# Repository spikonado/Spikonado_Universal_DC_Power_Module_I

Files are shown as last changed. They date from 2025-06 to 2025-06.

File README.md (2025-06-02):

# Spikonado Universal DC Power Module I

The [Spikonado Universal DC Power Module I](https://spikonado.com/product/spikonado-universal-dc-power-module-i) is a versatile and high-current buck converter designed to power your most demanding electronics projects. It efficiently (92.7%) converts a wide **13-24** DC input into three stable, dedicated outputs:

- **12V @ 4A**
- **5V @ 10A**
- **3.3V @ 8A**

This module is perfect for robotics, embedded systems, single-board computers (SBCs), custom test jigs, and any application requiring reliable multi-voltage power.<br>
Further enhancing its flexibility, the board includes USB-C and USB-A outputs.<br>
What's more, we have also included EN and PG pins through which you can control the board using a microcontroller and also attach a switch to the board.

The board also includes the following protections:

1. Over Current Limit (OCL) - Protects the board from overloads by limiting the output current.
2. Undervoltage Lockout (UVLO) - When the input voltage on VIN falls below the required voltage, the particular voltage output shuts off.
3. Thermal Shutdown - When any of the buck converter ICs included on the board get too hot, the particular voltage output shuts off.
4. Undervoltage and Overvoltage Protection (UVP & OVP) (Not included for 12V output) - When the output voltage falls too low or goes too high than the desired voltage, the output is discharged and latched.

## 📂 About this Repository

This repository is your central hub for all information, design files, and resources related to the Spikonado Universal DC Power Module I. Our aim is to provide everything you need to understand, use, and even build upon this product.

You'll find:

- `docs/`: Comprehensive documentation, including datasheets, specifications, and user guides.
- `hardware_design/`: Complete KiCad project design files – schematics and PCB layout for the board.

## Accessing the Documentation

The `docs/` directory contains the source files for our comprehensive product documentation. For the best reading experience, with all formatting and interactive elements correctly rendered, please view the built version on our [website](https://docs.spikonado.com/Spikonado_Universal_DC_Power_Module_I).

While you can browse the raw files in the `docs/` directory on GitHub, they are primarily intended for those contributing to the documentation or exploring its source structure.

## 🤝 Contributing

Contributions, issues, and feature requests are welcome! Feel free to check existing issues or open a new one.

## 📄 License

This product is open source!

Please review the following files for license information:

- `hardware_design/LICENSE.md`

If you have any questions or concerns related to licensing, please email support at support@spikonado.com.

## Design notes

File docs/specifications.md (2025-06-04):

# Specifications

## Maximum Current Ratings

- USB-A Outputs: 1.5A
- USB-C Outputs: 5A (Detected as 3A by smart devices connected to it)
- Scew Terminals: Same as the maximum current rating for their specific votage output
- PG: Less than 20mA

## Design Specifications

- [3D Model](https://github.com/spikonado/Spikonado_Universal_DC_Power_Module_I/blob/main/hardware_design/Spikonado_Universal_DC_Power_Module_I/Spikonado_Universal_DC_Power_Modul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)
- [Board Dimensions](https://github.com/spikonado/Spikonado_Universal_DC_Power_Module_I/blob/main/hardware_design/Spikonado_Universal_DC_Power_Module_I/dimensions.pdf)
- [Board Circuit Schematic](https://github.com/spikonado/Spikonado_Universal_DC_Power_Module_I/blob/main/hardware_design/Spikonado_Universal_DC_Power_Module_I/schematic.pdf)

## More Specifications

Datasheets of the buck converter ICs used in this board:

- 12V Output -> [LMR33640ADDAR](https://www.ti.com/lit/ds/symlink/lmr33640.pdf)
- 5V Output -> [TPS51396ARJER](https://www.ti.com/lit/ds/symlink/tps51397a.pdf)
- 3.3V Output -> [TPS51396ARJER](https://www.ti.com/lit/ds/symlink/tps51396a.pdf)

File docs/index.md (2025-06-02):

<script type="module" src="https://ajax.googleapis.com/ajax/libs/model-viewer/3.5.0/model-viewer.min.js"></script>

# Overview and Basic Usage

The [Spikonado Universal DC Power Module I](https://spikonado.com/product/spikonado-universal-dc-power-module-i) is a versatile and high-current buck converter designed to power your most demanding electronics projects. It efficiently (92.7%) converts a wide **13-24V** DC input into three stable, dedicated outputs:

- **12V @ 4A**
- **5V @ 10A**
- **3.3V @ 8A**

<figure markdown>
  <model-viewer alt="3D View of Spikonado Universal DC Power Module I" src="./assets/3d_model/Spikonado_Universal_DC_Power_Module_I.glb" camera-controls autoplay style="width: 500px; height: 300px;">
  </model-viewer>
  <figcaption markdown>3D View of Spikonado Universal DC Power Module I</figcaption>
</figure>

This module is perfect for robotics, embedded systems, single-board computers (SBCs), custom test jigs, and any application requiring reliable multi-voltage power.<br>
Further enhancing its flexibility, the board includes USB-C and USB-A outputs.<br>
What's more, we have also included EN and PG pins through which you can control the board using a microcontroller and also attach a switch to the board.

The board also includes the following protections:

1. Over Current Limit (OCL) - Protects the board from overloads by limiting the output current.
2. Undervoltage Lockout (UVLO) - When the input voltage on VIN falls below the required voltage, the particular voltage output shuts off.
3. Thermal Shutdown - When any of the buck converter ICs included on the board get too hot, the particular voltage output shuts off.
4. Undervoltage and Overvoltage Protection (UVP & OVP) (Not included for 12V output) - When the output voltage falls too low or goes too high than the desired voltage, the output is discharged and latched.

## Setting it Up

You must have recieved the following components in your package, when ordering from us:

1. [Spikonado Universal DC Power Module I](https://spikonado.com/product/spikonado-universal-dc-power-module-i) - x1
2. 2.54mm 1x2 Pin Male Header Strip - x3
3. 2.54mm 1x2 Pin Female Header Strip - x3
4. 2.54mm 1x1 Pin Male Header Strip - x3
5. 2.54mm 1x1 Pin Female Header Strip - x3
6. 5.0mm 1x2 Pin Screw Terminal Block - x4
7. 2.54mm 1x2 Pin Female Jumper - x3

Solder the headers and screw terminals onto your board as you desire.<br>
After soldering, it is recommended to use a multimeter to check that no shorts have been made by you during the soldering process.

Then, on the 3 EN pin pairs attach the jumpers or make a solder connection (not recommended) between the 2 pins of each pair if you aren't soldering the EN male headers onto your board. If soldering the female headers, you can also use male to male jumper wires to make the connection.

## Basic Usage

You need to first solder / screw (Screw Terminal) in two wires from your DC power output (ex. battery pack or wall adapter), into the VIN and GND ports of the board.<br>
You should now see all the 3 LEDs on the output terminals of the board lit, this means that all the outputs are working.<br>
You can now connect any DC load onto the output terminals of the board by soldering, screwing (Screw Terminal) or plugging (USB-C / USB-A) it in.

## Next Steps

Have a look at [What are EN and PG?](what_are_en_and_pg.md) to learn how to use those pins.<br>

## Related Resources

Have a look at [Specifications](specifications.md) to know more about the board's inner circuit alongside precise information on voltage and current ratings.

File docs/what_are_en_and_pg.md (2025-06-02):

# What are EN and PG?

## EN - Enable

There are 3 pairs of EN pins on the board. EN1 for 12V, EN2 for 5V, and EN3 for 3.3V.

You are supposed to short every pair of pins in order to turn on the respective outputs. So, if for example, you would like to add a switch to the board, you can simply connect it between the two pins. Whenever the switch is off, that particular voltage output will be off and when it is on, that particular voltage output will be on.

You can also control this on and off functionality through a microcontroller's digital / GPIO pins by simply not shorting the EN pair of pins together and instead connecting the digital / GPIO pin of your microcontroller to the pin right under which the EN label is.<br>
By simply setting the pin's mode to OUTPUT and turning the pin HIGH (1.2V to 5.5V) and LOW (-0.3V to 0.3V), you can turn the buck converter's voltage outputs on and off respectively.

## PG - Power Good

There are 3 PG pins on the board. PG1 for 12V, PG2 for 5V, and PG3 for 3.3V.

You can connect these pins to a microcontroller's pins and set the mode of the latter to INPUT.

The PG pins output LOW (0V) during fault conditions like OVP, UVP, UVLO, and thermal shutdown or when the converter is off / starting. Do note that the PG pins do not output LOW during Over Current Limit (OCL).<br>
The rest of the time the PG pins output HIGH (3.2 to 3.4, usually 3.3).

The PG output and status of each buck converter included in the board (12V, 5V, 3.3V) is different, one of the voltage outputs may be under fault conditions while the others may be wokring just fine.

## Related Resources

You can look at [Specifications](specifications.md) to know more about when the various fault conditions are triggered and to also know the startup time for each voltage output.

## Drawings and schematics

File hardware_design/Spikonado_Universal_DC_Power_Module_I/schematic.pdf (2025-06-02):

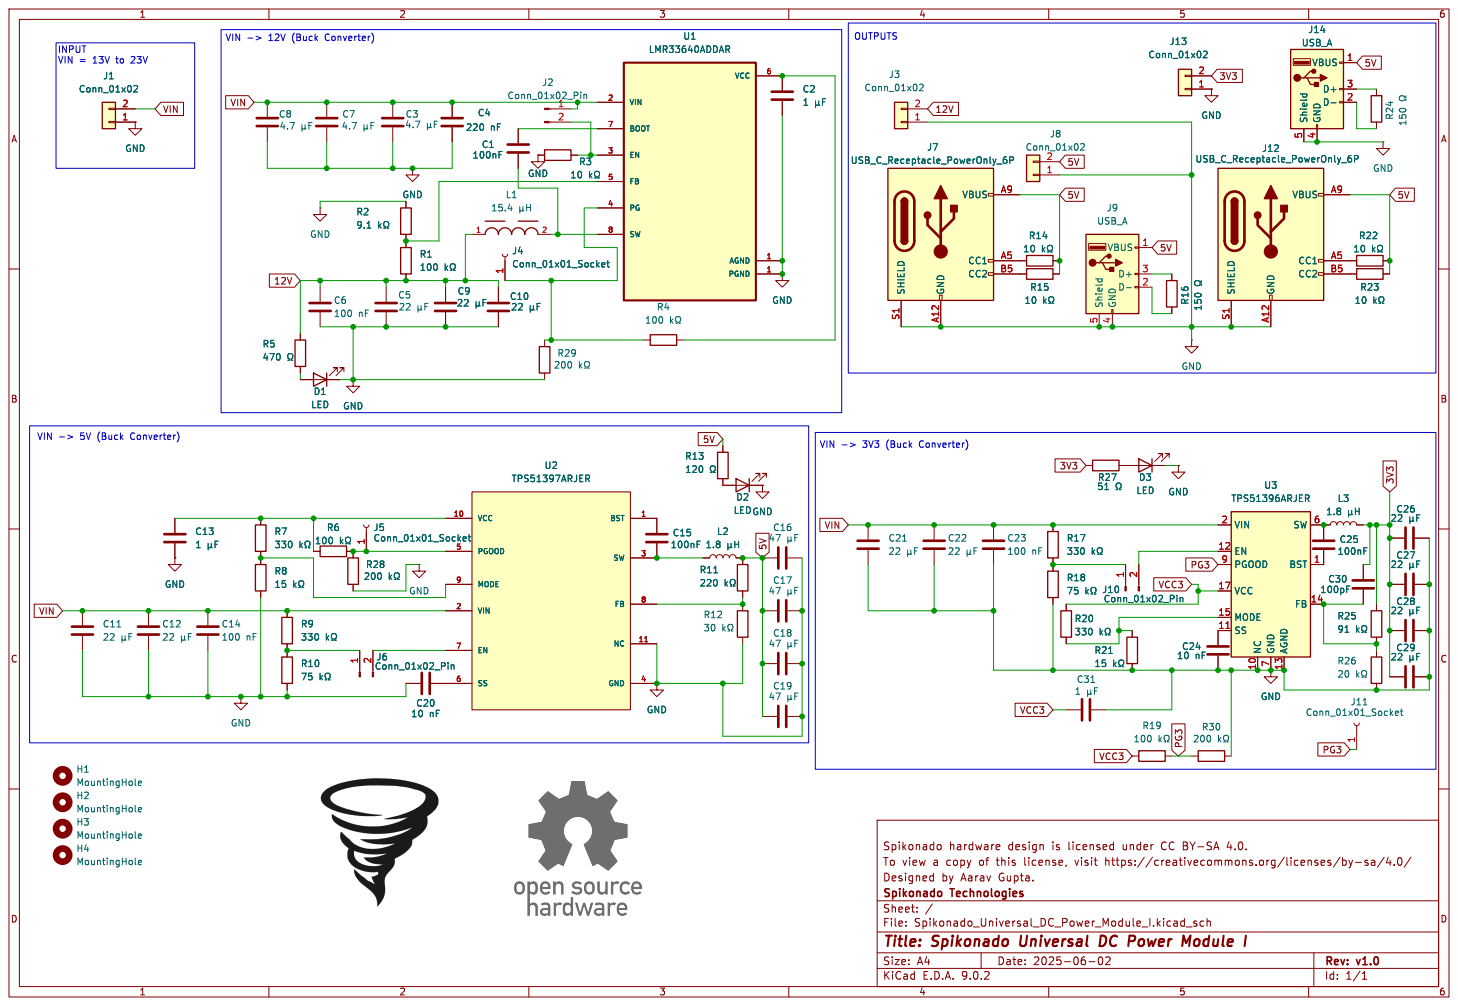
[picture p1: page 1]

INPUT VIN = 13V to 23V GND

10 þÿk© GND R16 150 þÿ© GND Shield

7 FB 14 VCC 17 SS 11 NC 10 AGND 13 SW 6 BST 1 U3 TPS51396ARJER

7 FB 14 VCC 17 SS 11 NC 10 AGND 13 SW 6 BST 1 R18

Designed by Aarav Gupta. To view a copy of this license, visit | | https://creativecommons.org/licenses/by-sa/4.0/

Technologies Id: 1/1 Title: Spikonado Universal DC Power Module I File: Spikonado_Universal_DC_Power_Module_I.kicad_sch Sheet: / Spikonado

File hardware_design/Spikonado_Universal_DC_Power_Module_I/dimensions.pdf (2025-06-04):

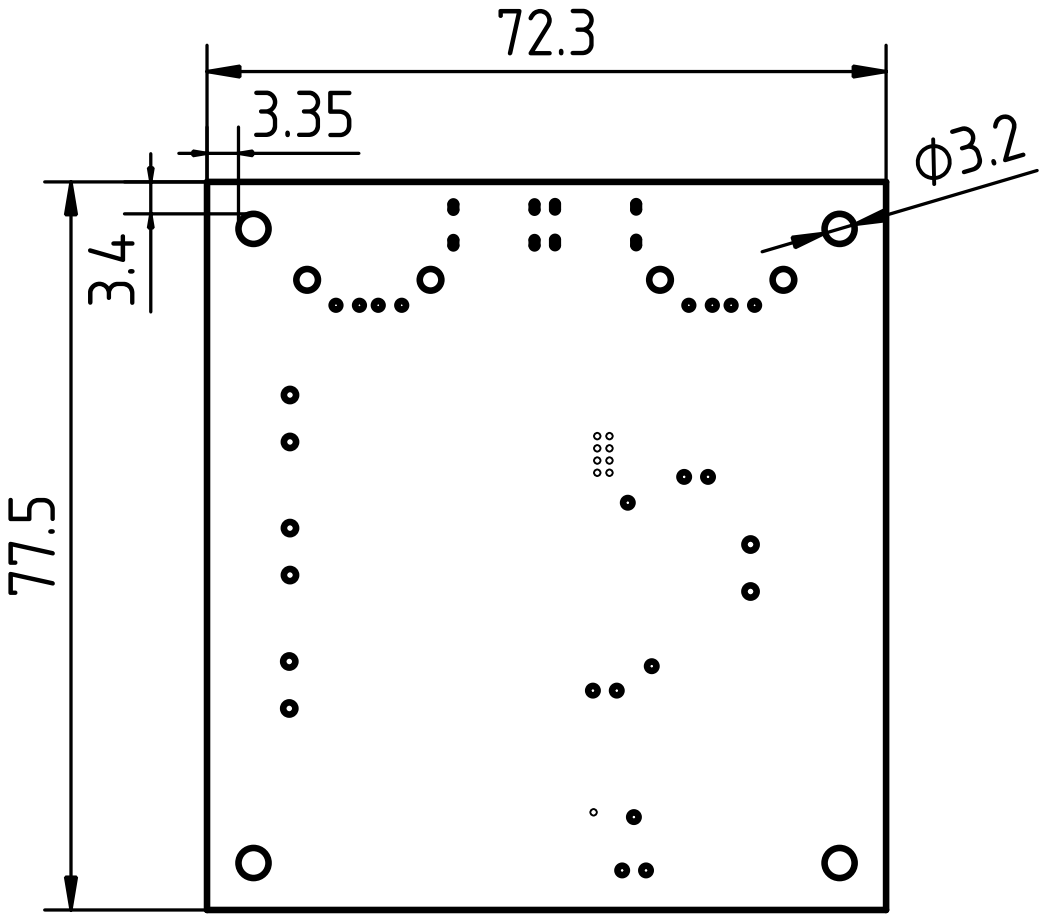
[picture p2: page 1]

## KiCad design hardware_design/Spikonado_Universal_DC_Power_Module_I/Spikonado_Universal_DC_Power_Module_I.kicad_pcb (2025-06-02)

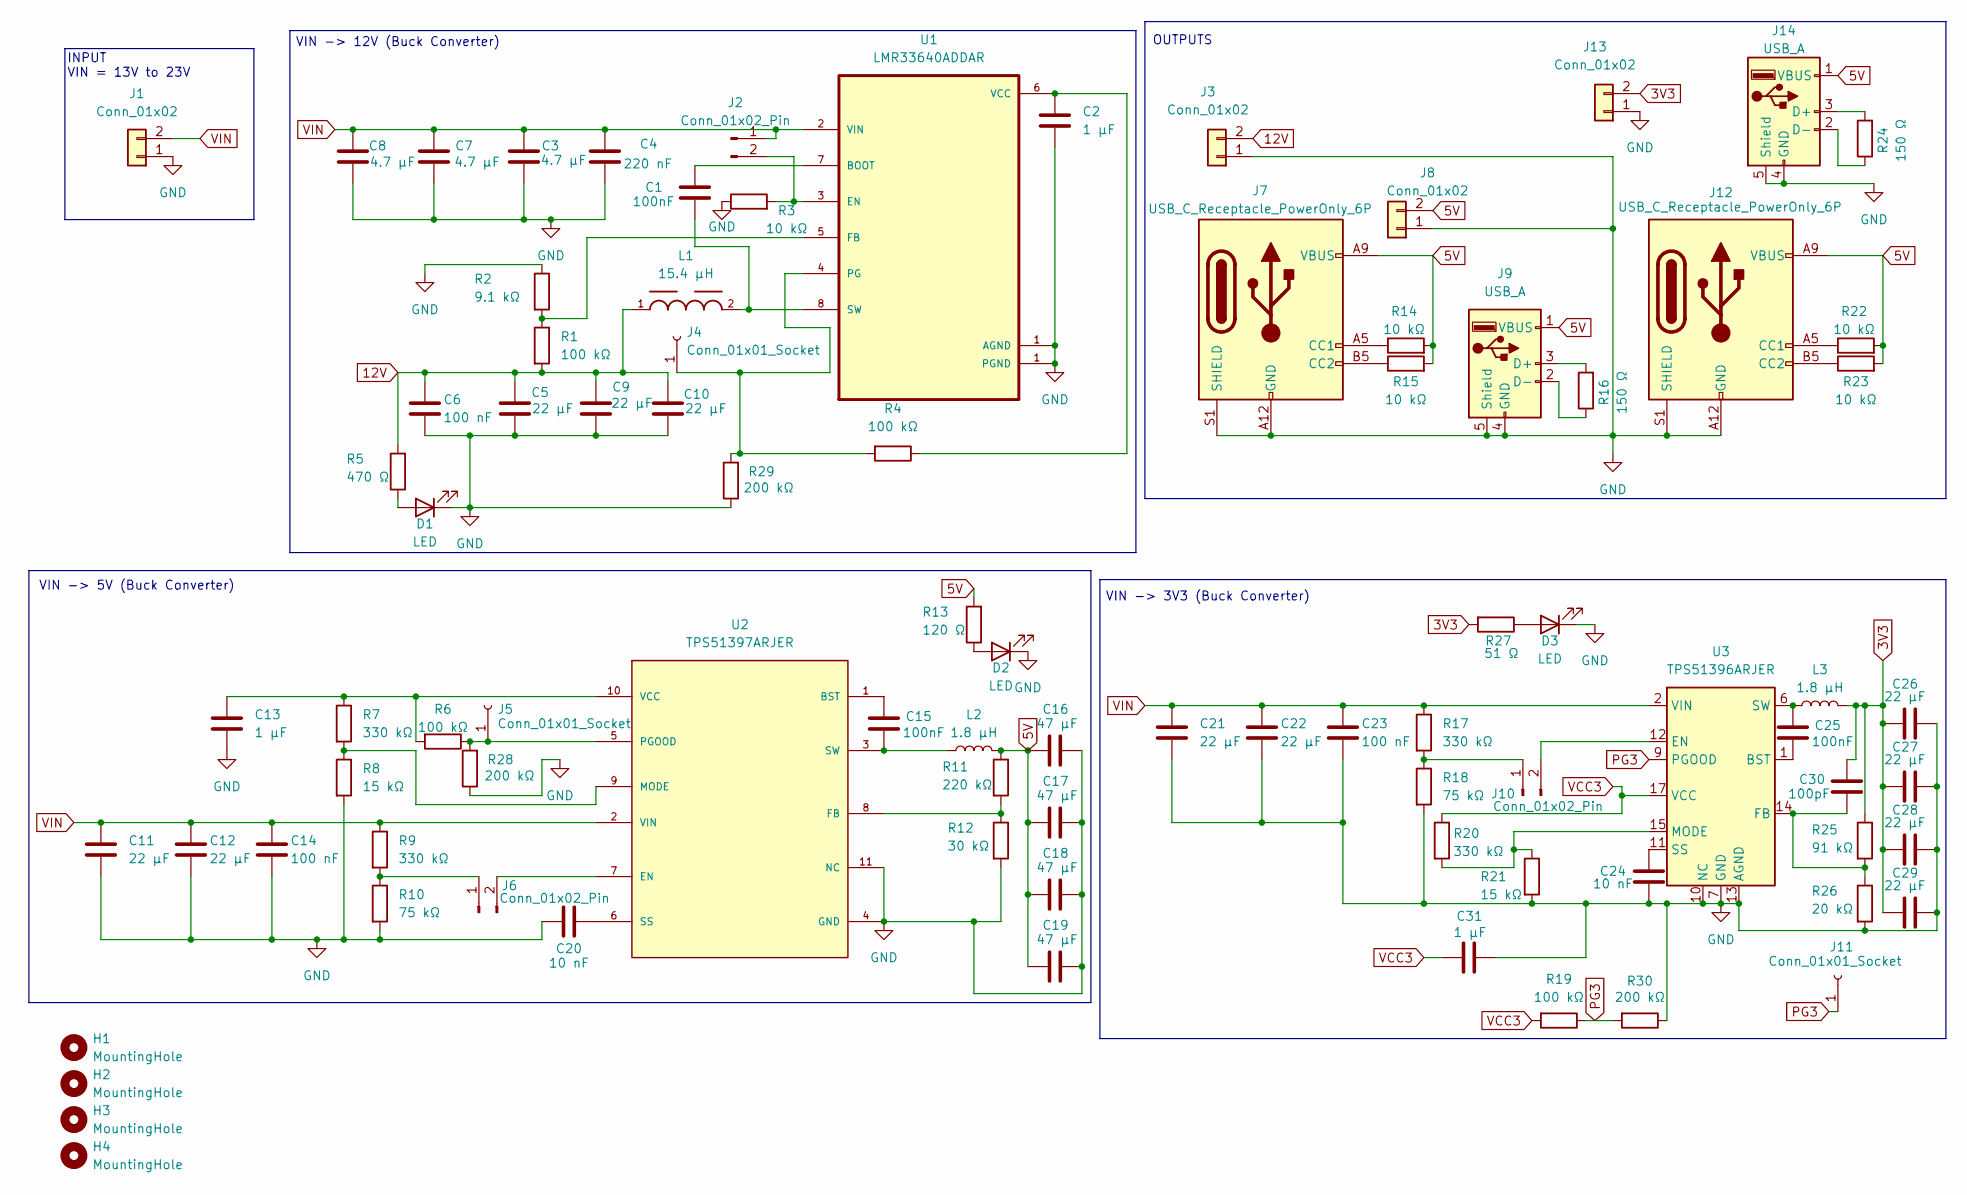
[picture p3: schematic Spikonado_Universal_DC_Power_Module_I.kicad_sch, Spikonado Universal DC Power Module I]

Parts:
C1, C15, C25: 100nF; C_0805_2012Metric
C2, C13, C31: 1 μF; C_0402_1005Metric
C3, C7, C8: 4.7 μF; C_1206_3216Metric
C4: 220 nF; C_0805_2012Metric
C5, C9, C10: 22 μF; C_0805_2012Metric
C6, C14, C23: 100 nF; C_0805_2012Metric
C11, C12, C21, C22, C26, C27, C28, C29: 22 μF; C_1206_3216Metric
C16, C17, C18, C19: 47 μF; C_1206_3216Metric
C20, C24: 10 nF; C_0805_2012Metric
C30: 100pF; C_0805_2012Metric
D1, D2, D3: LED; LED_0603_1608Metric
H1, H2, H3, H4: MountingHole; MountingHole_3.2mm_M3
J1, J3, J8, J13: Conn_01x02; TerminalBlock_MaiXu_MX126-5.0-02P_1x02_P5.00mm
J2, J6, J10: Conn_01x02_Pin; PinHeader_1x02_P2.54mm_Vertical
J4, J5, J11: Conn_01x01_Socket; PinSocket_1x01_P2.54mm_Vertical
J7, J12: USB_C_Receptacle_PowerOnly_6P; USB_C_Receptacle_GCT_USB4125-xx-x_6P_TopMnt_Horizontal
J9, J14: USB_A; USB_A_Connfly_DS1095
L1: 15.4 µH; WE-HCI_1365
L2, L3: 1.8 μH; IND_IHLP_5050_FD_VIS
R1, R4, R6, R19: 100 kΩ; R_0805_2012Metric
R2: 9.1 kΩ; C_0603_1608Metric
R3, R14, R15, R22, R23: 10 kΩ; R_0805_2012Metric
R5: 470 Ω; R_0805_2012Metric
R7, R9, R17, R20: 330 kΩ; R_0603_1608Metric
R8, R21: 15 kΩ; R_0603_1608Metric
R10, R18: 75 kΩ; R_0603_1608Metric
R11: 220 kΩ; R_0805_2012Metric
R12: 30 kΩ; R_0805_2012Metric
R13: 120 Ω; R_0805_2012Metric
R16, R24: 150 Ω; R_0805_2012Metric
R25: 91 kΩ; R_0603_1608Metric
R26: 20 kΩ; R_0603_1608Metric
R27: 51 Ω; R_0805_2012Metric
R28, R29, R30: 200 kΩ; R_0805_2012Metric
U1: LMR33640ADDAR; VREG_LM5017MR_NOPB
U2: TPS51397ARJER; RJE0020B-MFG
U3: TPS51396ARJER; Texas_RJE0020A_VQFN-20-1EP_3x3mm_P0.45mm_EP0.675x0.76mm_The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

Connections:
3V3: C26.2, C27.2, C28.2, C29.2, C30.1, J13.2, L3.2, R25.1, R27.2
5V: C16.1, C17.1, C18.1, C19.1, J7.A9 (VBUS), J7.B9 (VBUS), J8.2, J9.1 (VBUS), J12.A9 (VBUS), J12.B9 (VBUS), J14.1 (VBUS), L2.2, R11.1, R13.2, R14.2, R15.2, R22.2, R23.2
12V: C5.2, C6.1, C9.1, C10.2, J3.2, L1.1, R1.2, R5.2
GND: C2.2, C3.1, C4.2, C5.1, C6.2, C7.1, C8.1, C9.2, C10.1, C11.1, C12.1, C13.2, C14.2, C16.2, C17.2, C18.2, C19.2, C20.2, C21.1, C22.1, C23.2, C24.2, C26.1, C27.1, C28.1, C29.1, C31.2, D1.1 (K), D2.1 (K), D3.1 (K), J1.1, J3.1, J7.A12 (GND), J7.B12 (GND), J7.S1 (SHIELD), J8.1, J9.4 (GND), J9.5 (Shield), J12.A12 (GND), J12.B12 (GND), J12.S1 (SHIELD), J13.1, J14.4 (GND), J14.5 (Shield), R2.1, R3.1, R8.2, R10.2, R12.2, R18.2, R21.2, R26.2, R28.1, R29.1, R30.1, U1.1 (PGND), U2.4 (GND), U2.11 (NC), U3.7 (GND), U3.8 (GND), U3.10 (NC), U3.13 (AGND), U3.16 (NC), U3.18 (GND), U3.21 (GND)
unnamed: C25.2, L3.1, U3.6 (SW), U3.19 (SW), U3.20 (SW)
unnamed: D1.2 (A), R5.1
unnamed: D2.2 (A), R13.1
unnamed: D3.2 (A), R27.1
unnamed: J2.2, R3.2, U1.3 (EN)
unnamed: J4.1, R4.2, R29.2, U1.4 (PG)
unnamed: J5.1, R6.1, R28.2, U2.5 (PGOOD)
unnamed: J6.1, R9.2, R10.1
unnamed: J6.2, U2.7 (EN)
unnamed: J7.A5 (CC1), R14.1
unnamed: J7.B5 (CC2), R15.1
unnamed: J9.3 (D+), R16.2
unnamed: J9.2 (D-), R16.1
unnamed: J10.1, R17.2, R18.1
unnamed: J10.2, U3.12 (EN)
unnamed: J12.A5 (CC1), R22.1
unnamed: J12.B5 (CC2), R23.1
unnamed: J14.3 (D+), R24.2
unnamed: J14.2 (D-), R24.1
unnamed: C1.1, U1.7 (BOOT)
unnamed: R1.1, R2.2, U1.5 (FB)
unnamed: C1.2, L1.2, U1.8 (SW)
unnamed: C2.1, R4.1, U1.6 (VCC)
unnamed: C15.2, U2.1 (BST)
unnamed: R11.2, R12.1, U2.8 (FB)
unnamed: R7.2, R8.1, U2.9 (MODE)
unnamed: C20.1, U2.6 (SS)
unnamed: C15.1, L2.1, U2.3 (SW)
unnamed: C13.1, R6.2, R7.1, U2.10 (VCC)
unnamed: C25.1, U3.1 (BST)
unnamed: C30.2, R25.2, R26.1, U3.14 (FB)
unnamed: R20.2, R21.1, U3.15 (MODE)
unnamed: C24.1, U3.11 (SS)
PG3: J11.1, R19.1, R30.2, U3.9 (PGOOD)
VCC3: C31.1, R19.2, R20.1, U3.17 (VCC)
VIN: C3.2, C4.1, C7.2, C8.2, C11.2, C12.2, C14.1, C21.2, C22.2, C23.1, J1.2, J2.1, R9.1, R17.1, U1.2 (VIN), U2.2 (VIN), U3.2 (VIN), U3.3 (VIN), U3.4 (VIN), U3.5 (VIN)

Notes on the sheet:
VIN -> 12V (Buck Converter)
OUTPUTS
VIN -> 3V3 (Buck Converter)
VIN -> 5V (Buck Converter)
INPUT VIN = 13V to 23V

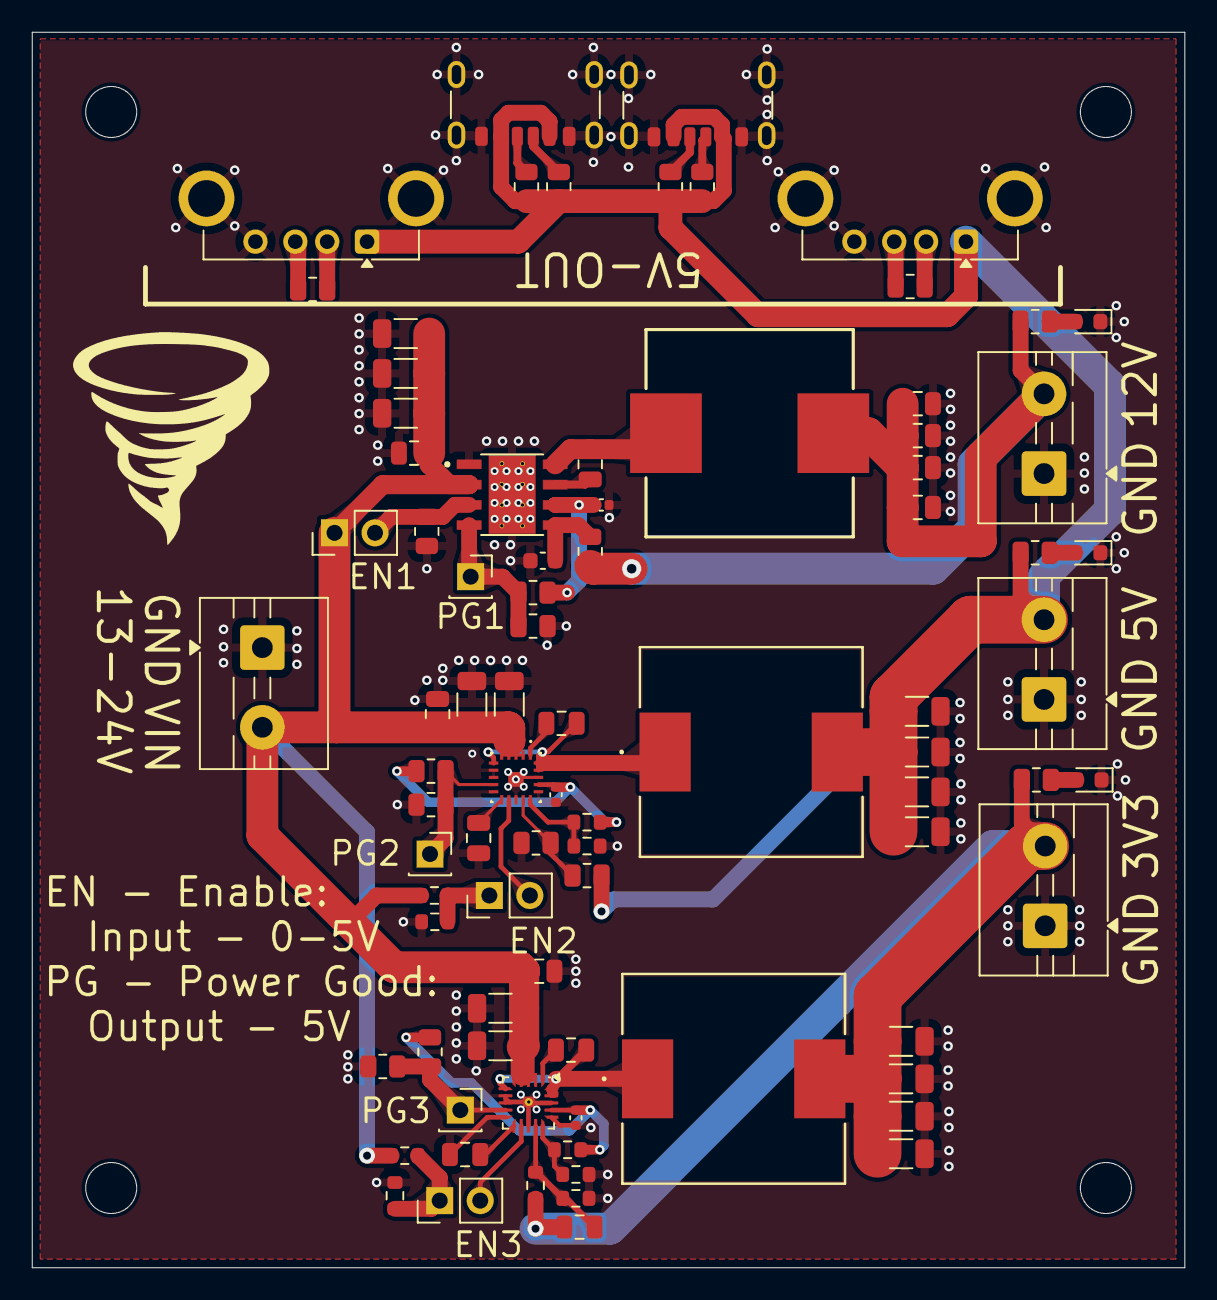
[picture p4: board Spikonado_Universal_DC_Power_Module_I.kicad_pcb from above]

Board: 4 copper layers, 72.3 x 77.5 mm, 88 parts (0 on the bottom side), 40 nets.

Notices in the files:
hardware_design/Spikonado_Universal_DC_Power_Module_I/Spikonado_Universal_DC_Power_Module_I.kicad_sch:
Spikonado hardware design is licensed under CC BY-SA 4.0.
